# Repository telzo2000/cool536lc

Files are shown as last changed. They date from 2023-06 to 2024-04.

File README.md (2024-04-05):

# cool536lc

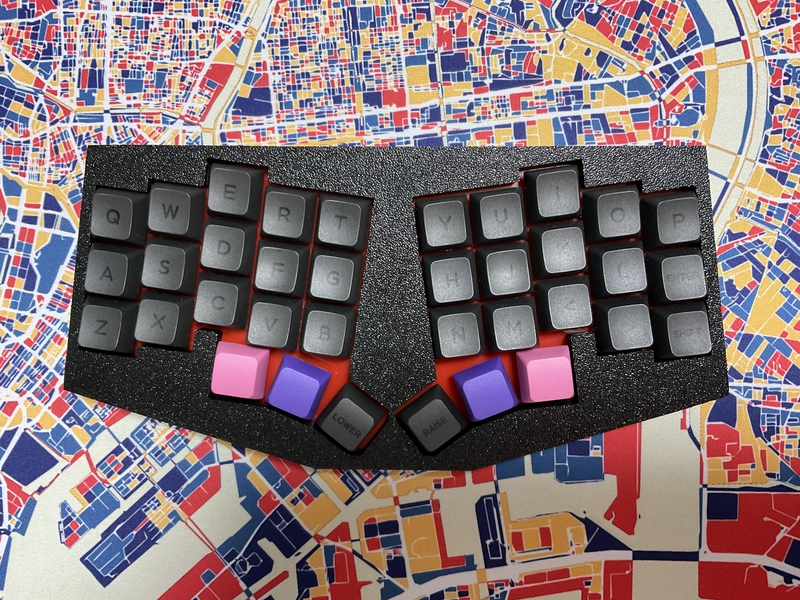
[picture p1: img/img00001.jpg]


<br>
cool536lc is small keyboard.<br>
This keyboard has columns layout.<br>
cool536lc's 36 keys can do it all.<br>

<br>

# firmware

https://github.com/telzo2000/cool536lc/tree/main/firmware

<br>

# buildguide

https://github.com/telzo2000/cool536lc/blob/main/buildguide_for_cool536lc.md

<br>

## Pats list

| No. | Patrs | Quantity | remarks | Suppliers | Cost |
|--|--|--|--|--|--|
|番号|名前|数|備考|調達先|参考価格（送料込）|<br>
|1|PCB|1|36key AlicLayout|[elecrow](https://www.elecrow.com)<br>[JLCPCB](https://jlcpcb.com)<br>[ALLPCB](https://www.allpcb.com)|５枚で20〜30ドル|<br>
|2|Switch Plate|1||[elecrow](https://www.elecrow.com)<br>[JLCPCB](https://jlcpcb.com)<br>[ALLPCB](https://www.allpcb.com)|５枚で20〜30ドル|<br>
|3|RP-2040Zero|1||[Talp Keyboard](https://talpkeyboard.net)|800円|
|4|Swith socket<br>スイッチソケット|36|cherry MX互換|[遊舎工房](https://yushakobo.jp)<br>[Talp Keyboard](https://talpkeyboard.net)<br>[Daily Craft Keyboard](https://shop.dailycraft.jp)等|10個で165円程度|
|5|Diode<br>ダイオード|36|リードタイプでもSMDでも可|[遊舎工房](https://yushakobo.jp)<br>[Talp Keyboard](https://talpkeyboard.net)<br>[Daily Craft Keyboard](https://shop.dailycraft.jp)等|100個で220円程度から|
|6|TopCase|1|3D Print|||
|7|BottomCase|1|3D Print||

In addition, you will need a USB cable, keycaps, etc.
<br>
この他に、USBケーブル、キーキャップ等が必要です。
<br>

## License

MIT license,However, I do not allow ProtieusKeebs to use the data of cool536lc and other keyboards I have designed, because I feel he has no respect for the designers.

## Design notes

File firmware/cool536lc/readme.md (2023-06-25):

# cool536lc

cool536lc

*A short description of the keyboard/project*

* Keyboard Maintainer: [m.ki](https://github.com/telzo2000)
* Hardware Supported: *The PCBs, controllers supported*
* Hardware Availability: *Links to where you can find this hardware*

Make example for this keyboard (after setting up your build environment):

    make cool536lc:default

Flashing example for this keyboard:

    make cool536lc:default:flash

See the [build environment setup](https://docs.qmk.fm/#/getting_started_build_tools) and the [make instructions](https://docs.qmk.fm/#/getting_started_make_guide) for more information. Brand new to QMK? Start with our [Complete Newbs Guide](https://docs.qmk.fm/#/newbs).

## Bootloader

Enter the bootloader in 3 ways:

* **Bootmagic reset**: Hold down the key at (0,0) in the matrix (usually the top left key or Escape) and plug in the keyboard
* **Physical reset button**: Briefly press the button on the back of the PCB - some may have pads you must short instead
* **Keycode in layout**: Press the key mapped to `QK_BOOT` if it is available

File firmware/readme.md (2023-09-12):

# Firmware

Support QMK_Firmware.
<br>
QMK_Firmwareに対応。
<br>
<br>
Compatible with [Remap](https://remap-keys.app/catalog/okRojRTIKaIxCGuHC3c3) and [VIA](https://usevia.app/).
<br>
[Remap](https://remap-keys.app/catalog/okRojRTIKaIxCGuHC3c3)と[VIA](https://usevia.app/)に対応。
<br>
File name: cool536lc_via.uf2
<br>
<br>
Compatible with [VIAL](https://get.vial.today/).
<br>
[VIAL](https://get.vial.today/)に対応。
<br>
File name: cool536lc_vial.uf2
<br>
20230912　The version of qmk_Firmware now corresponds to 0.22.

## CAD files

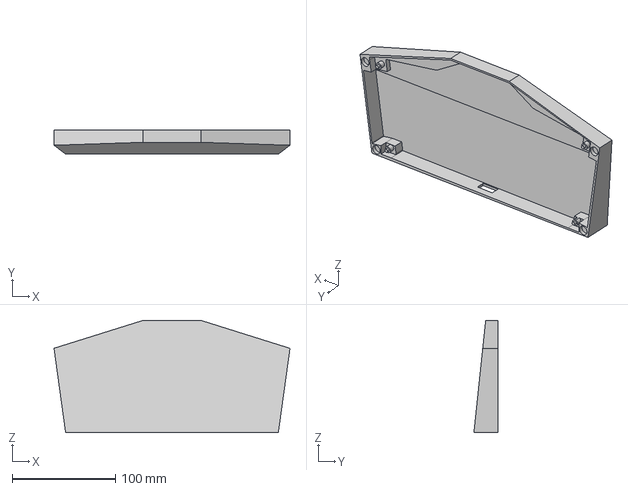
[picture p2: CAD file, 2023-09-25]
case_design/step/cool536lc_bottom_newversion v16.step
228.6 x 23.5 x 108.8 mm

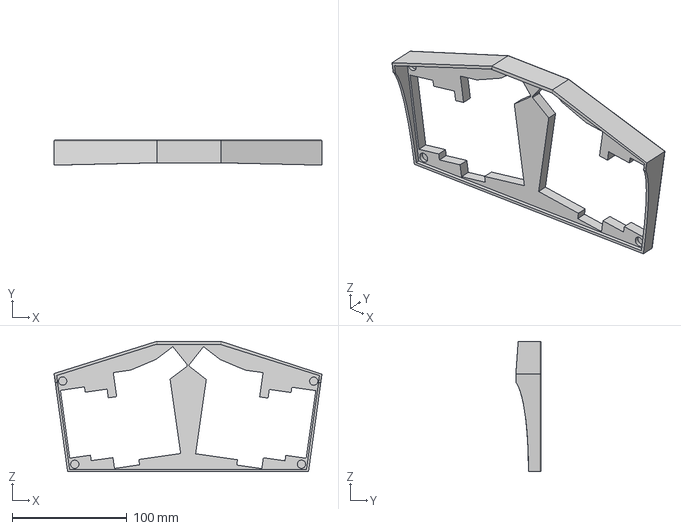
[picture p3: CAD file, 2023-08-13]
case_design/step/cool536lc_top_newversion v9.step
233.1 x 22.0 x 113.5 mm

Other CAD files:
case_design/stl/cool536lc_bpttom_newversion v15.stl
case_design/stl/cool536lc_bpttom_newversion v13.stl
case_design/step/cool536lc_bottom_newversion v13.step
case_design/stl/cool536lc_top_newversion v9.stl

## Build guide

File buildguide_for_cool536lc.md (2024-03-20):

## Build guide

## Firmware

###  QMK_FIRMWARE

参考<br>

https://github.com/telzo2000/Hello_keyboard/blob/main/readme_about_firmware.md

[Here](https://github.com/telzo2000/cool536lc/tree/main/firmware)

<br>

[remap](https://remap-keys.app/catalog/okRojRTIKaIxCGuHC3c3)

<br>

Note! When selecting layers in Remap, we have confirmed that depending on the position of the mouse cursor, you may not be able to move the layer even if you click. If you move the mouse cursor slightly to the left of the layer number, as shown in the image, it will respond more easily.
<br>
注意！　Remapでのレイヤー選択の際、マウスカーソルの位置によってはクリックしてもレイヤー移動ができない現象が確認できています。画像のように、レイヤー番号のやや左側付近にマウスカーソルを移動すると、反応しやすいです。
<br>

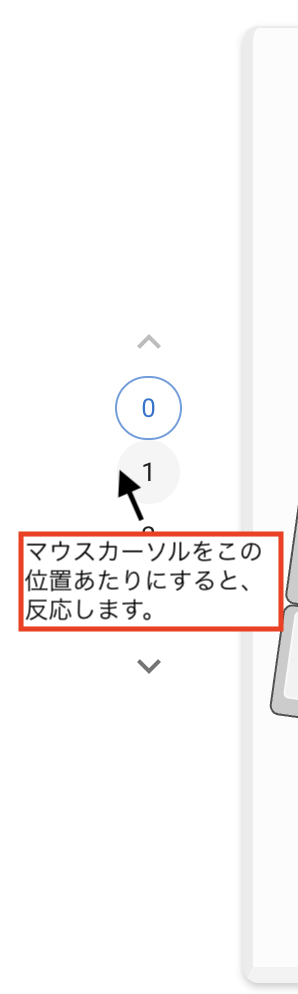
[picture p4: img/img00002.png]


## Build 1

### 1 Diode soldering

Solder the diodes to the back of PCB.
<br>
PCBの裏面にダイオードのハンダ付けをします。
<br>
There are lead type and SMD diodes.
<br>
ダイオードはリードタイプか、SMDがあります。
<br>
Here, we will explain the lead type soldering.
<br>
ここでは、リードタイプのハンダ付けの説明をします。
<br>

Use a lead bender to bend the legs of the diode.
<br>
リードベンダーを使い、ダイオードの足を曲げます。
<br>
Insert the diode into the board.
<br>
ダイオードを基板に挿しこみます。
<br>

Please pay attention to the orientation of the diode.
<br>
ダイオードの向きに注意してください。
<br>

Secure the diode with masking tape, then face up.
<br>
マスキングテープでダイオードを固定してから、表面を上にします。
<br>
Solder the protruding legs.
<br>
はみ出ている足部分に、ハンダ付けをします。
<br>
After soldering, use nippers to cut off the protruding legs.
<br>
はんだ付けが終わったら、はみ出ている足をニッパーで切り取ってください。
<br>

[８倍速　Diodeハンダ付け動画](https://youtu.be/Yaodh2-XxV4)

<br>
<br>

### 2 Soldering switch sockets

Solder the switch sockets on the back side.
<br>
裏面にスイッチソケットのハンダ付けをします。
<br>

[８倍速　Switch socketハンダ付け動画](https://youtu.be/E__mHvmIXQo)

<br><br>

### 3　Soldering RP-2040Zero  

The side on which components such as the boot button and reset button of RP-2040Zero are mounted is the front side, and the other side is the back side.
<br>
RP-2040Zeroのbootボタンやresetボタンなど部品実装されている面を表面とし、反対側を裏面とします。
<br>
Place the back side of the PCB and the back side of the RP-2040Zero facing each other and solder the respective terminals.
<br>
PCBの裏面とRP-2040Zeroの裏面が向かい合うようにして置き、それぞれの端子をハンダ付けします。
<br>
<br>

### 4 Instorlling QMK＿Firmware

Install QMK_Firmware from your PC to RP-2040Zero.
<br>
QMK_FirmwareをPCからRP-2040Zeroにインストールしてください。
<br>
<br>
① Download https://github.com/telzo2000/cool536lc/blob/main/firmware/cool536lc_via.uf2　to your PC.
<br>
①https://github.com/telzo2000/cool536lc/blob/main/firmware/cool536lc_via.uf2　をPCにダウンロードしておく。

<br><br>
② Connect the PC and RP-2040Zero with a USB cable.
<br>
②PCとRP-2040ZeroをUSBケーブルで繋ぐ。
<br><br>
③Press the reset button while pressing the boost button on the RP-2040Zero.
<br>
③RP-2040Zeroのboostボタン押しながら、resetボタンを押す。
<br><br>
④Since there is a folder of RP-2040Zero on the PC screen, drag and drop the downloaded cool536lc.uf2 there.
<br>
④PC画面にはRP-2040Zeroのフォルダがあるので、そこに、ダウンロードしたcool536lc.uf2をドラッグアンドドロップする。
<br><br>

⑤Check if it is recognized by connecting to remap. Edit the keymap accordingly.
<br>
⑤remapに繋いで認識するかどうか確認する。合わせてキーマップの編集をする。

### Build 2(case)

### 1 Case

I will explain using a case printed by stereolithography of black resin ordered from JLCPCB. The procedure is basically the same for cases printed with Ankemake M5 for home use.
<br>
JLCPCBに発注したブラックレジンの光造形で印刷されたケースを使って説明します。家庭用AnkemakeM5で印刷したケースでも作業の手順は、基本的に同じです。
<br>
<br>
Fix the [magnets](https://www.amazon.co.jp/gp/product/B09B7BSXC4/ref=ppx_yo_dt_b_asin_title_o02_s00?ie=UTF8&th=1) to the five dents inside the case with an adhesive or the like. There are 4 in the top case and 4 in the bottom case for a total of 8.Please pay attention to the polarity of the magnet. Make sure the top case and bottom case are magnetically attached.
<br>
ケースの内側にある４つの凹みに[磁石](https://www.amazon.co.jp/gp/product/B09B7BSXC4/ref=ppx_yo_dt_b_asin_title_o02_s00?ie=UTF8&th=1)を接着剤などで固定します。トップケースに４箇所、ボトムケースに４箇所の合計８箇所です。
極性に注意してください。トップケースとボトムケースが磁力で着くようにしてください。
<br>


As shown in the image below, attach rubber O-rings to the four protrusions on the bottom case. This makes it a gasket mount. You can do without the O-ring, but the PCB may move up and down inside the case.
<br>
下の画像のように、ボトムケースに4箇所の凸部にゴムのO-ringを装着します。これによりガスケットマウントとなります。O-ringはなくても大丈夫ですが、ケース内で、PCBが上下に動く可能性があります。
<br>


The O-ring in the image is [this product](https://www.amazon.co.jp/gp/product/B07G4SM5SM/ref=ppx_yo_dt_b_asin_title_o03_s00?ie=UTF8&psc=1).
<br>
画像のO-ringは[この商品](https://www.amazon.co.jp/gp/product/B07G4SM5SM/ref=ppx_yo_dt_b_asin_title_o03_s00?ie=UTF8&psc=1)です。
<br>
<br>
Place the hole in the switch plate on the O-ring. And it is completed by covering the top case.
<br>
スイッチプレートの穴をO-ringに載せます。そして、トップケースを被せて完成です。
<br>
<br><br>
Note: If you are concerned about the thumb cluster key sinking, it is a good idea to install a 5mm thick sponge inside.
<br>
注意：もし、サムクラスタのキーの沈みが気になる場合、内部に5mm厚のスポンジを装着するとよいでしょう。

Welcome to the world of 36 keys.
<br>
36キーの世界へようこそ。
<br>
